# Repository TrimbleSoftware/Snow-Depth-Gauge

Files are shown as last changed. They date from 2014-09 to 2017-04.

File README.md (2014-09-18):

Snow-Depth-Gauge
================

Ultrasonic Wireless Snow Depth Gauge 

Source for Teensy 3.1 Firmware and Eagle 6.5.0 Schematic, 
PCB Layout and Parts list BOM for Trimble Ultrasonic Wireless Snow Depth Gauge.

Uses PRJC Teensy 3.1 microcontroller, MaxBotix ultrasonic sensor and
XBee Series 1 for wireless connectivity.

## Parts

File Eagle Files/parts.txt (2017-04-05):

Mfg Part Num	Mfg Name	VID	Vendor Part Num	Description	Pkg Code
LNJ337W83RA	Panasonic Electronic Components	DK	LNJ337W83RACT-ND	LED GREEN HIGH BRIGHT ESS SMD	0603
LNJ437W84RA	Panasonic Electronic Components	DK	LNJ437W84RACT-ND	LED AMBER HIGH BRIGHT ESS SMD	0603
LNJ237W82RA	Panasonic Electronic Components	DK	LNJ237W82RACT-ND	LED RED HIGH BRIGHT ESS SMD	0603
C1206C104K4RACTU	Kemet	DK	399-9305-1-ND	CAP CER 0.1UF 16V 10% X7R 1206	C3216
KTR18EZPF1102	Rohm Semiconductor	DK	RHM11KAICT-ND	RES 11K OHM 1/4W 1% 1206 SMD	R3216
KTR18EZPF2002	Rohm Semiconductor	DK	RHM20.0KAICT-ND	RES 20K OHM 1/4W 1% 1206 SMD	R3216
MMBT2222A	Fairchild Semiconductor	DK	MMBT2222AFSCT-ND	TRANSISTOR GP NPN AMP SOT-23	SOT23
MMBT4403	Fairchild Semiconductor	DK	MMBT4403FSCT-ND	TRANSISTOR GP PNP AMP SOT-23	SOT23
0022292041	Molex Inc	DK	WM2746-ND	CONN HEADER 4POS .100 VERT GOLD	*
0022292031	Molex Inc	DK	WM2745-ND	CONN HEADER 3POS .100 VERT GOLD	*
0022292021	Molex Inc	DK	WM2744-ND	CONN HEADER 2POS .100 VERT GOLD	*
KTR18EZPF68R0	Rohm Semiconductor	DK	RHM68AICT-ND	RES SMD 68 OHM 1% 1/4W 1206	R3216
KTR18EZPJ103	Rohm Semiconductor	DK	RHM10KPCT-ND	RES 10K OHM 1/4W 5% 1206 SMD	R3216
KTR18EZPF1002	Rohm Semiconductor	DK	RHM10.0KAICT-ND	RES SMD 10K OHM 1% 1/4W 1206	R3216
KTR18EZPF2702	Rohm Semiconductor	DK	RHM27KAICT-ND	RES SMD 27K OHM 1% 1/4W 1206	R3216
KTR18EZPJ104	Rohm Semiconductor	DK	RHM100KPCT-ND	RES 100K OHM 1/4W 5% 1206 SMD	R3216
KTR18EZPJ102	Rohm Semiconductor	DK	RHM1.0KPCT-ND	RES 1K OHM 1/4W 5% 1206 SMD	R3216
KTR18EZPF4701	Rohm Semiconductor	DK	RHM4.7KAICT-ND	RES SMD 4.7K OHM 1% 1/4W 1206 SMD	R3216
KTR18EZPJ221	Rohm Semiconductor	DK	RHM220PCT-ND	RES 220 OHM 1/4W 5% 1206 SMD	R3216
831-87-010-10-001101	Preci-Dip	DK	1212-1314-ND	SOCKET 4.2 MM SOLDER TAIL SINGLE	*
310-87-114-41-001101	Preci-Dip	DK	1212-1101-ND	14 Position Socket Connector 0.100" (2.54mm) Through Hole Gold	*
351-10-114-00-004101	Preci-Dip	DK	1212-1153-ND	14 Positions Header, Unshrouded Connector 0.100" (2.54mm) Through Hole Gold	*
310-87-105-41-001101	Preci-Dip	DK	1212-1094-ND	5 Position Socket Connector 0.100" (2.54mm) Through Hole Gold	*
960114-6202-AR	3M	DK	3M9519-ND	CONN SOCKET SGL VERT 14POS GOLD	*
960105-6202-AR	3M	DK	3M9516-ND	CONN SOCKET SGL VERT 5POS GOLD	*
961114-6404-AR	3M	DK	3M9453-ND	CONN HEADER VERT SGL 14POS GOLD	*
961105-6404-AR	3M	DK	3M9450-ND	CONN HEADER VERT SGL 5POS GOLD	*
PRT-09919	Sparkfun	SF	MOLEX_TO_MOLEX_13_II_07	Molex Jumper 3 Wire Assembly 6" Long	*
PRT-09920	Sparkfun	SF	MOLEX_TO_MOLEX_13_II_07	Molex Jumper 4 Wire Assembly 6" Long	*
XB24-AUI-001	Digi International/Maxstream	DK	XB24-AUI-001-ND	MODULE 802.15.4 1MW W/U.FL CONN	*
RN-UFL-SMA6	Microchip Technology	DK	740-1031-ND	CABLE COAX W/UFL RPSMA 6"	*
W1038	Pulse Electronics Corporation	DK	553-1476-ND	ANTENNA 2.4GHZ HG R-SMA BLK 6.6"	*
MB7957	MaxBotix Inc.	MB	MB7957	HR-MaxTemp MB7957	*
MB7374	MaxBotix Inc.	MB	MB7374	HRXL-MaxSonar - WRS Series Ultrasonic Snow Depth Sensor MB7374	*
TEENSY31	PRJC.COM	PR	TEENSY31	Teensy USB Board, Version 3.1	*
TEENSY32	PRJC.COM	PR	TEENSY32	Teensy USB Board, Version 3.2	*
S2B-PH-SM4-TB(LF)(SN)	JST Sales America Inc	DK	455-1749-1-ND	CONN HEADER PH SIDE 2POS 2MM SMD	*

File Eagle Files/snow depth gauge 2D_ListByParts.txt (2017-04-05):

Part      Value           Attributes Package          Description                                                                     Part Num              Mfg Name                        VID Vendor Part Num         Description                                                                 Pkg Code XREF 
BATT      5VDC                       JST-PH-2-SMT-RA  JST 2-Pin Connectors of various flavors                                         S2B-PH-SM4-TB(LF)(SN) JST Sales America Inc           DK  455-1749-1-ND           CONN HEADER PH SIDE 2POS 2MM SMD                                            *        REF37
C1        0.1uF                      C3216            CAPACITOR, American symbol                                                      C1206C104K4RACTU      Kemet                           DK  399-9305-1-ND           CAP CER 0.1UF 16V 10% X7R 1206                                              C3216    REF4 
D1        GREEN                      LED-0603         Various green LEDs                                                              LNJ337W83RA           Panasonic Electronic Components DK  LNJ337W83RACT-ND        LED GREEN HIGH BRIGHT ESS SMD                                               0603     REF1 
D2        YELLOW                     LED-0603         Yellow SMD LEDs                                                                 LNJ437W84RA           Panasonic Electronic Components DK  LNJ437W84RACT-ND        LED AMBER HIGH BRIGHT ESS SMD                                               0603     REF2 
D3        RED                        LED-0603         Assorted Red LEDs                                                               LNJ237W82RA           Panasonic Electronic Components DK  LNJ237W82RACT-ND        LED RED HIGH BRIGHT ESS SMD                                                 0603     REF3 
JP1       TO MAXBOTIX                MOLEX-1X4        Header 4                                                                        0022292041            Molex Inc                       DK  WM2746-ND               CONN HEADER 4POS .100 VERT GOLD                                             *        REF9 
JP1-1     BOM-ENTRY                  *                BOM ENTRY                                                                       PRT-09920             Sparkfun                        SF  MOLEX_TO_MOLEX_13_II_07 Molex Jumper 4 Wire Assembly 6" Long                                        *        REF29
JP2       M02POLAR                   MOLEX-1X2        Standard 2-pin 0.1" header. Use with                                            0022292021            Molex Inc                       DK  WM2744-ND               CONN HEADER 2POS .100 VERT GOLD                                             *        REF11
JP3       To LiPo Charger            MOLEX-1X4        Header 4                                                                        0022292041            Molex Inc                       DK  WM2746-ND               CONN HEADER 4POS .100 VERT GOLD                                             *        REF9 
JP4       M02POLAR                   MOLEX-1X2        Standard 2-pin 0.1" header. Use with                                            0022292021            Molex Inc                       DK  WM2744-ND               CONN HEADER 2POS .100 VERT GOLD                                             *        REF11
Q1        MMBT2222A                  SOT23-BEC        NPN Transistror                                                                 MMBT2222A             Fairchild Semiconductor         DK  MMBT2222AFSCT-ND        TRANSISTOR GP NPN AMP SOT-23                                                SOT23    REF7 
Q2        MMBT4403LT1SMD             SOT23-BEC        PNP Transistror                                                                 MMBT4403              Fairchild Semiconductor         DK  MMBT4403FSCT-ND         TRANSISTOR GP PNP AMP SOT-23                                                SOT23    REF8 
Q3        MMBT2222A                  SOT23-BEC        NPN Transistror                                                                 MMBT2222A             Fairchild Semiconductor         DK  MMBT2222AFSCT-ND        TRANSISTOR GP NPN AMP SOT-23                                                SOT23    REF7 
Q4        MMBT2222A                  SOT23-BEC        NPN Transistror                                                                 MMBT2222A             Fairchild Semiconductor         DK  MMBT2222AFSCT-ND        TRANSISTOR GP NPN AMP SOT-23                                                SOT23    REF7 
R1        100K                       R3216            RESISTOR, American symbol                                                       KTR18EZPJ104          Rohm Semiconductor              DK  RHM100KPCT-ND           RES 100K OHM 1/4W 5% 1206 SMD                                               R3216    REF16
R2        10K                        R3216            RESISTOR, American symbol                                                       KTR18EZPJ103          Rohm Semiconductor              DK  RHM10KPCT-ND            RES 10K OHM 1/4W 5% 1206 SMD                                                R3216    REF13
R3        10K                        R3216            RESISTOR, American symbol                                                       KTR18EZPJ103          Rohm Semiconductor              DK  RHM10KPCT-ND            RES 10K OHM 1/4W 5% 1206 SMD                                                R3216    REF13
R4        27K                        R3216            RESISTOR, American symbol                                                       KTR18EZPJ273          *                               *   *                       *                                                                           *        *    
R5        220                        R3216            RESISTOR, American symbol                                                       KTR18EZPJ221          Rohm Semiconductor              DK  RHM220PCT-ND            RES 220 OHM 1/4W 5% 1206 SMD                                                R3216    REF19
R6        68                         R3216            RESISTOR, American symbol                                                       KTR18EZPF68R0         Rohm Semiconductor              DK  RHM68AICT-ND            RES SMD 68 OHM 1% 1/4W 1206                                                 R3216    REF12
R7        68                         R3216            RESISTOR, American symbol                                                       KTR18EZPF68R0         Rohm Semiconductor              DK  RHM68AICT-ND            RES SMD 68 OHM 1% 1/4W 1206                                                 R3216    REF12
R8        68                         R3216            RESISTOR, American symbol                                                       KTR18EZPF68R0         Rohm Semiconductor              DK  RHM68AICT-ND            RES SMD 68 OHM 1% 1/4W 1206                                                 R3216    REF12
R9        1K                         R3216            RESISTOR, American symbol                                                       KTR18EZPJ102          Rohm Semiconductor              DK  RHM1.0KPCT-ND           RES 1K OHM 1/4W 5% 1206 SMD                                                 R3216    REF17
R10       10K                        R3216            RESISTOR, American symbol                                                       KTR18EZPJ103          Rohm Semiconductor              DK  RHM10KPCT-ND            RES 10K OHM 1/4W 5% 1206 SMD                                                R3216    REF13
R11       4.7K                       R3216            RESISTOR, American symbol                                                       KTR18EZPF4701         Rohm Semiconductor              DK  RHM4.7KAICT-ND          RES SMD 4.7K OHM 1% 1/4W 1206 SMD                                           R3216    REF18
SENSOR1-1 BOM-ENTRY                  *                BOM ENTRY                                                                       MB7374                MaxBotix Inc.                   MB  MB7374                  HRXL-MaxSonar - WRS Series Ultrasonic Snow Depth Sensor MB7374              *        REF34
SNESOR1-2 BOM-ENTRY                  *                BOM ENTRY                                                                       MB7957                MaxBotix Inc.                   MB  MB7957                  HR-MaxTemp MB7957                                                           *        REF33
U1        TEENSY 3.2                 TEENSY_3.1_BASIC Footprint for Teensy 3.1 board using all pin connections on the outer perimeter TEENSY32              PRJC.COM                        PR  TEENSY32                Teensy USB Board, Version 3.2                                               *        REF36
U1-1      BOM-ENTRY                  *                BOM ENTRY                                                                       310-87-114-41-001101  Preci-Dip                       DK  1212-1101-ND            14 Position Socket Connector 0.100" (2.54mm) Through Hole Gold              *        REF21
U1-2      BOM-ENTRY                  *                BOM ENTRY                                                                       310-87-114-41-001101  Preci-Dip                       DK  1212-1101-ND            14 Position Socket Connector 0.100" (2.54mm) Through Hole Gold              *        REF21
U1-3      BOM-ENTRY                  *                BOM ENTRY                                                                       310-87-105-41-001101  Preci-Dip                       DK  1212-1094-ND            5 Position Socket Connector 0.100" (2.54mm) Through Hole Gold               *        REF23
U1-4      BOM-ENTRY                  *                BOM ENTRY                                                                       351-10-114-00-004101  Preci-Dip                       DK  1212-1153-ND            14 Positions Header, Unshrouded Connector 0.100" (2.54mm) Through Hole Gold *        REF22
U1-5      BOM-ENTRY                  *                BOM ENTRY                                                                       351-10-114-00-004101  Preci-Dip                       DK  1212-1153-ND            14 Positions Header, Unshrouded Connector 0.100" (2.54mm) Through Hole Gold *        REF22
U1-6      BOM-ENTRY                  *                BOM ENTRY                                                                       351-10-114-00-004101  Preci-Dip                       DK  1212-1153-ND            14 Positions Header, Unshrouded Connector 0.100" (2.54mm) Through Hole Gold *        REF22
U2        XBEE-1B1                   XBEE-1           Xbee module footprints                                                          XB24-AUI-001          Digi International/Maxstream    DK  XB24-AUI-001-ND         MODULE 802.15.4 1MW W/U.FL CONN                                             *        REF30
U2-1      BOM-ENTRY                  *                BOM ENTRY                                                                       831-87-010-10-001101  Preci-Dip                       DK  1212-1314-ND            SOCKET 4.2 MM SOLDER TAIL SINGLE                                            *        REF20
U2-2      BOM-ENTRY                  *                BOM ENTRY                                                                       831-87-010-10-001101  Preci-Dip                       DK  1212-1314-ND            SOCKET 4.2 MM SOLDER TAIL SINGLE                                            *        REF20
U2-3      BOM-ENTRY                  *                BOM ENTRY                                                                       RN-UFL-SMA6           Microchip Technology            DK  740-1031-ND             CABLE COAX W/UFL RPSMA 6                                                    *        REF31
U2-4      BOM-ENTRY                  *                BOM ENTRY                                                                       W1038                 Pulse Electronics Corporation   DK  553-1476-ND             ANTENNA 2.4GHZ HG R-SMA BLK 6.6                                             *        REF32

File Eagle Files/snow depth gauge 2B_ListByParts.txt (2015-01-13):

Part      Value           Attributes Package          Description                                                                     Part Num              Mfg Name                        VID Vendor Part Num         Description                                                    Pkg Code XREF 
BATT      5VDC                       JST-PH-2-SMT-RA  JST 2-Pin Connectors of various flavors                                         S2B-PH-SM4-TB(LF)(SN) JST Sales America Inc           DK  455-1749-1-ND           CONN HEADER PH SIDE 2POS 2MM SMD                               *        REF33
C1        0.1uF                      C3216            CAPACITOR, American symbol                                                      C1206C104K4RACTU      Kemet                           DK  399-9305-1-ND           CAP CER 0.1UF 16V 10% X7R 1206                                 C3216    REF4 
D1        GREEN                      LED-0603         Various green LEDs                                                              LNJ337W83RA           Panasonic Electronic Components DK  LNJ337W83RACT-ND        LED GREEN HIGH BRIGHT ESS SMD                                  0603     REF1 
D2        YELLOW                     LED-0603         Yellow SMD LEDs                                                                 LNJ437W84RA           Panasonic Electronic Components DK  LNJ437W84RACT-ND        LED AMBER HIGH BRIGHT ESS SMD                                  0603     REF2 
D3        RED                        LED-0603         Assorted Red LEDs                                                               LNJ237W82RA           Panasonic Electronic Components DK  LNJ237W82RACT-ND        LED RED HIGH BRIGHT ESS SMD                                    0603     REF3 
JP1       TO MAXBOTIX                MOLEX-1X4        Header 4                                                                        0022292041            Molex Inc                       DK  WM2746-ND               CONN HEADER 4POS .100 VERT GOLD                                *        REF9 
JP1-1     BOM-ENTRY                  *                BOM ENTRY                                                                       PRT-09920             Sparkfun                        SF  MOLEX_TO_MOLEX_13_II_07 Molex Jumper 4 Wire Assembly 6" Long                           *        REF26
JP2       M02POLAR                   MOLEX-1X2        Standard 2-pin 0.1" header. Use with                                            0022292021            Molex Inc                       DK  WM2744-ND               CONN HEADER 2POS .100 VERT GOLD                                *        REF11
JP3       To LiPo Charger            MOLEX-1X4        Header 4                                                                        0022292041            Molex Inc                       DK  WM2746-ND               CONN HEADER 4POS .100 VERT GOLD                                *        REF9 
Q1        MMBT2222A                  SOT23-BEC        NPN Transistror                                                                 MMBT2222A             Fairchild Semiconductor         DK  MMBT2222AFSCT-ND        TRANSISTOR GP NPN AMP SOT-23                                   SOT23    REF7 
Q2        MMBT4403LT1SMD             SOT23-BEC        PNP Transistror                                                                 MMBT4403              Fairchild Semiconductor         DK  MMBT4403FSCT-ND         TRANSISTOR GP PNP AMP SOT-23                                   SOT23    REF8 
Q3        MMBT2222A                  SOT23-BEC        NPN Transistror                                                                 MMBT2222A             Fairchild Semiconductor         DK  MMBT2222AFSCT-ND        TRANSISTOR GP NPN AMP SOT-23                                   SOT23    REF7 
Q4        MMBT2222A                  SOT23-BEC        NPN Transistror                                                                 MMBT2222A             Fairchild Semiconductor         DK  MMBT2222AFSCT-ND        TRANSISTOR GP NPN AMP SOT-23                                   SOT23    REF7 
R1        100K                       R3216            RESISTOR, American symbol                                                       KTR18EZPJ104          Rohm Semiconductor              DK  RHM100KPCT-ND           RES 100K OHM 1/4W 5% 1206 SMD                                  R3216    REF17
R2        10K                        R3216            RESISTOR, American symbol                                                       KTR18EZPJ103          Rohm Semiconductor              DK  RHM10KPCT-ND            RES 10K OHM 1/4W 5% 1206 SMD                                   R3216    REF13
R3        10K                        R3216            RESISTOR, American symbol                                                       KTR18EZPF1002         Rohm Semiconductor              DK  RHM10.0KAICT-ND         RES SMD 10K OHM 1% 1/4W 1206                                   R3216    REF14
R4        27K                        R3216            RESISTOR, American symbol                                                       KTR18EZPF2702         Rohm Semiconductor              DK  RHM27KAICT-ND           RES SMD 27K OHM 1% 1/4W 1206                                   R3216    REF16
R5        220                        R3216            RESISTOR, American symbol                                                       KTR18EZPJ221          Rohm Semiconductor              DK  RHM220PCT-ND            RES 220 OHM 1/4W 5% 1206 SMD                                   R3216    REF19
R6        68                         R3216            RESISTOR, American symbol                                                       KTR18EZPJ680          Rohm Semiconductor              DK  RHM68PCT-ND             RES 68 OHM 1/4W 5% 1206 SMD                                    R3216    REF12
R7        68                         R3216            RESISTOR, American symbol                                                       KTR18EZPJ680          Rohm Semiconductor              DK  RHM68PCT-ND             RES 68 OHM 1/4W 5% 1206 SMD                                    R3216    REF12
R8        68                         R3216            RESISTOR, American symbol                                                       KTR18EZPJ680          Rohm Semiconductor              DK  RHM68PCT-ND             RES 68 OHM 1/4W 5% 1206 SMD                                    R3216    REF12
R9        1K                         R3216            RESISTOR, American symbol                                                       KTR18EZPJ102          Rohm Semiconductor              DK  RHM1.0KPCT-ND           RES 1K OHM 1/4W 5% 1206 SMD                                    R3216    REF18
R10       10K                        R3216            RESISTOR, American symbol                                                       KTR18EZPJ103          Rohm Semiconductor              DK  RHM10KPCT-ND            RES 10K OHM 1/4W 5% 1206 SMD                                   R3216    REF13
SENSOR1-1 BOM-ENTRY                  *                BOM ENTRY                                                                       MB7374                MaxBotix Inc.                   MB  MB7374                  HRXL-MaxSonar - WRS Series Ultrasonic Snow Depth Sensor MB7374 *        REF31
SNESOR1-2 BOM-ENTRY                  *                BOM ENTRY                                                                       MB7957                MaxBotix Inc.                   MB  MB7957                  HR-MaxTemp MB7957                                              *        REF30
U1        TEENSY 3.1                 TEENSY_3.1_BASIC Footprint for Teensy 3.1 board using all pin connections on the outer perimeter TEENSY31              PRJC.COM                        PR  TEENSY31                Teensy USB Board, Version 3.1                                  *        REF32
U1-1      BOM-ENTRY                  *                BOM ENTRY                                                                       961114-6404-AR        3M                              DK  3M9453-ND               CONN HEADER VERT SGL 14POS GOLD                                *        REF23
U1-2      BOM-ENTRY                  *                BOM ENTRY                                                                       961114-6404-AR        3M                              DK  3M9453-ND               CONN HEADER VERT SGL 14POS GOLD                                *        REF23
U1-3      BOM-ENTRY                  *                BOM ENTRY                                                                       961105-6404-AR        3M                              DK  3M9450-ND               CONN HEADER VERT SGL 5POS GOLD                                 *        REF24
U2        XBEE-1B1                   XBEE-1           Xbee module footprints                                                          XB24-AUI-001          Digi International/Maxstream    DK  XB24-AUI-001-ND         MODULE 802.15.4 1MW W/U.FL CONN                                *        REF27
U2-1      BOM-ENTRY                  *                BOM ENTRY                                                                       831-87-010-10-001101  Preci-Dip                       DK  1212-1314-ND            SOCKET 4.2 MM SOLDER TAIL SINGLE                               *        REF20
U2-2      BOM-ENTRY                  *                BOM ENTRY                                                                       831-87-010-10-001101  Preci-Dip                       DK  1212-1314-ND            SOCKET 4.2 MM SOLDER TAIL SINGLE                               *        REF20
U2-3      BOM-ENTRY                  *                BOM ENTRY                                                                       RN-UFL-SMA6           Microchip Technology            DK  740-1031-ND             CABLE COAX W/UFL RPSMA 6                                       *        REF28
U2-4      BOM-ENTRY                  *                BOM ENTRY                                                                       W1038                 Pulse Electronics Corporation   DK  553-1476-ND             ANTENNA 2.4GHZ HG R-SMA BLK 6.6                                *        REF29

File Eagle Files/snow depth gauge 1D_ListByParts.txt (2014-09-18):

Part      Value          Attributes Package          Description                                                                     Part Num             Mfg Name                        VID Vendor Part Num         Description                                                    Pkg Code XREF 
C1        0.1uF                     C3216            CAPACITOR, American symbol                                                      C1206C104K4RACTU     Kemet                           DK  399-9305-1-ND           CAP CER 0.1UF 16V 10% X7R 1206                                 1206     REF4 
D1        GREEN                     LED-0603         Various green LEDs                                                              LNJ337W83RA          Panasonic Electronic Components DK  LNJ337W83RACT-ND        LED GREEN HIGH BRIGHT ESS SMD                                  0603     REF1 
D2        YELLOW                    LED-0603         Yellow SMD LEDs                                                                 LNJ437W84RA          Panasonic Electronic Components DK  LNJ437W84RACT-ND        LED AMBER HIGH BRIGHT ESS SMD                                  0603     REF2 
D3        RED                       LED-0603         Assorted Red LEDs                                                               LNJ237W82RA          Panasonic Electronic Components DK  LNJ237W82RACT-ND        LED RED HIGH BRIGHT ESS SMD                                    0603     REF3 
JP1       TO MAXBOTIX               MOLEX-1X3_LOCK   Header 3                                                                        0022292031           Molex Inc                       DK  WM2745-ND               CONN HEADER 3POS .100 VERT GOLD                                2.54mm   REF9 
JP1-1     BOM-ENTRY                 *                BOM ENTRY                                                                       PRT-09919            Sparkfun                        SF  MOLEX_TO_MOLEX_13_II_07 Molex Jumper 3 Wire Assembly                                   2.54mm   REF20
Q1                                  SOT23-BEC        NPN Transistror                                                                 MMBT2222A            Fairchild Semiconductor         DK  MMBT2222AFSCT-ND        TRANSISTOR GP NPN AMP SOT-23                                   SOT-23   REF7 
Q2        MMBT4403LT1SMD            SOT23-BEC        PNP Transistror                                                                 MMBT4403             Fairchild Semiconductor         DK  MMBT4403FSCT-ND         TRANSISTOR GP PNP AMP SOT-23                                   SOT-23   REF8 
Q3                                  SOT23-BEC        NPN Transistror                                                                 MMBT2222A            Fairchild Semiconductor         DK  MMBT2222AFSCT-ND        TRANSISTOR GP NPN AMP SOT-23                                   SOT-23   REF7 
Q4                                  SOT23-BEC        NPN Transistror                                                                 MMBT2222A            Fairchild Semiconductor         DK  MMBT2222AFSCT-ND        TRANSISTOR GP NPN AMP SOT-23                                   SOT-23   REF7 
R1        100K                      R3216            RESISTOR, American symbol                                                       KTR18EZPJ104         Rohm Semiconductor              DK  RHM100KPCT-ND           RES 100K OHM 1/4W 5% 1206 SMD                                  1206     REF12
R2        10K                       R3216            RESISTOR, American symbol                                                       KTR18EZPJ103         Rohm Semiconductor              DK  RHM10KPCT-ND            RES 10K OHM 1/4W 5% 1206 SMD                                   1206     REF11
R3        11K                       R3216            RESISTOR, American symbol                                                       KTR18EZPF1102        Rohm Semiconductor              DK  RHM11KAICT-ND           RES 11K OHM 1/4W 1% 1206 SMD                                   1206     REF5 
R4        20K                       R3216            RESISTOR, American symbol                                                       KTR18EZPF2002        Rohm Semiconductor              DK  RHM20.0KAICT-ND         RES 20K OHM 1/4W 1% 1206 SMD                                   1206     REF6 
R5        220                       R3216            RESISTOR, American symbol                                                       KTR18EZPJ221         Rohm Semiconductor              DK  RHM220PCT-ND            RES 220 OHM 1/4W 5% 1206 SMD                                   1206     REF14
R6        68                        R3216            RESISTOR, American symbol                                                       KTR18EZPJ680         Rohm Semiconductor              DK  RHM68PCT-ND             RES 68 OHM 1/4W 5% 1206 SMD                                    1206     REF10
R7        68                        R3216            RESISTOR, American symbol                                                       KTR18EZPJ680         Rohm Semiconductor              DK  RHM68PCT-ND             RES 68 OHM 1/4W 5% 1206 SMD                                    1206     REF10
R8        68                        R3216            RESISTOR, American symbol                                                       KTR18EZPJ680         Rohm Semiconductor              DK  RHM68PCT-ND             RES 68 OHM 1/4W 5% 1206 SMD                                    1206     REF10
R9        1K                        R3216            RESISTOR, American symbol                                                       KTR18EZPJ102         Rohm Semiconductor              DK  RHM1.0KPCT-ND           RES 1K OHM 1/4W 5% 1206 SMD                                    1206     REF13
SENSOR1-1 BOM-ENTRY                 *                BOM ENTRY                                                                       MB7374               MaxBotix Inc.                   MB  MB7374                  HRXL-MaxSonar - WRS Series Ultrasonic Snow Depth Sensor MB7374 *        REF25
SNESOR1-2 BOM-ENTRY                 *                BOM ENTRY                                                                       MB7957               MaxBotix Inc.                   MB  MB7957                  HR-MaxTemp MB7957                                              *        REF24
U1        TEENSY 3.1                TEENSY_3.1_BASIC Footprint for Teensy 3.1 board using all pin connections on the outer perimeter TEENSY31             PRJC.COM                        PR  TEENSY31                Teensy USB Board, Version 3.1                                  *        REF26
U1-1      BOM-ENTRY                 *                BOM ENTRY                                                                       961114-6404-AR       3M                              DK  3M9453-ND               CONN HEADER VERT SGL 14POS GOLD                                2.54mm   REF18
U1-2      BOM-ENTRY                 *                BOM ENTRY                                                                       961114-6404-AR       3M                              DK  3M9453-ND               CONN HEADER VERT SGL 14POS GOLD                                2.54mm   REF18
U1-3      BOM-ENTRY                 *                BOM ENTRY                                                                       961105-6404-AR       3M                              DK  3M9450-ND               CONN HEADER VERT SGL 5POS GOLD                                 2.54mm   REF19
U2        XBEE-1B1                  XBEE-1           Xbee module footprints                                                          XB24-AUI-001         Digi International/Maxstream    DK  XB24-AUI-001-ND         MODULE 802.15.4 1MW W/U.FL CONN                                2.00mm   REF21
U2-1      BOM-ENTRY                 *                BOM ENTRY                                                                       831-87-010-10-001101 Preci-Dip                       DK  1212-1314-ND            SOCKET 4.2 MM SOLDER TAIL SINGLE                               2.00mm   REF15
U2-2      BOM-ENTRY                 *                BOM ENTRY                                                                       831-87-010-10-001101 Preci-Dip                       DK  1212-1314-ND            SOCKET 4.2 MM SOLDER TAIL SINGLE                               2.00mm   REF15
U2-3      BOM-ENTRY                 *                BOM ENTRY                                                                       RN-UFL-SMA6          Microchip Technology            DK  740-1031-ND             CABLE COAX W/UFL RPSMA 6                                       *        REF22
U2-4      BOM-ENTRY                 *                BOM ENTRY                                                                       W1038                Pulse Electronics Corporation   DK  553-1476-ND             ANTENNA 2.4GHZ HG R-SMA BLK 6.6                                *        REF23

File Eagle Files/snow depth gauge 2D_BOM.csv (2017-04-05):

Qty-4 | Part References | Value | Package | Mfg Part Num | Mfg Name | VID | Vendor Part Num | Description | Pkg Code | XREF
4 | C1 | 0.1uF | C3216 | C1206C104K4RACTU | Kemet | DK | 399-9305-1-ND | CAP CER 0.1UF 16V 10% X7R 1206 | C3216 | REF4
4 | R9 | 1K | R3216 | KTR18EZPJ102 | Rohm Semiconductor | DK | RHM1.0KPCT-ND | RES 1K OHM 1/4W 5% 1206 SMD | R3216 | REF17
4 | R11 | 4.7K | R3216 | KTR18EZPF4701 | Rohm Semiconductor | DK | RHM4.7KAICT-ND | RES SMD 4.7K OHM 1% 1/4W 1206 SMD | R3216 | REF18
4 | BATT | 5VDC | JST-PH-2-SMT-RA | S2B-PH-SM4-TB(LF)(SN) | JST Sales America Inc | DK | 455-1749-1-ND | CONN HEADER PH SIDE 2POS 2MM SMD | * | REF37
12 | R2, R3, R10 | 10K | R3216 | KTR18EZPJ103 | Rohm Semiconductor | DK | RHM10KPCT-ND | RES 10K OHM 1/4W 5% 1206 SMD | R3216 | REF13
4 | R4 | 27K | R3216 | ***PART# 'KTR18EZPJ273' NOT FOUND*** | * | * | * | * | * | *
12 | R6, R7, R8 | 68 | R3216 | KTR18EZPF68R0 | Rohm Semiconductor | DK | RHM68AICT-ND | RES SMD 68 OHM 1% 1/4W 1206 | R3216 | REF12
4 | R1 | 100K | R3216 | KTR18EZPJ104 | Rohm Semiconductor | DK | RHM100KPCT-ND | RES 100K OHM 1/4W 5% 1206 SMD | R3216 | REF16
4 | R5 | 220 | R3216 | KTR18EZPJ221 | Rohm Semiconductor | DK | RHM220PCT-ND | RES 220 OHM 1/4W 5% 1206 SMD | R3216 | REF19
4 | U1-3 | BOM-ENTRY | * | 310-87-105-41-001101 | Preci-Dip | DK | 1212-1094-ND | 5 Position Socket Connector 0.100" (2.54mm) Through Hole Gold | * | REF23
8 | U1-1, U1-2 | BOM-ENTRY | * | 310-87-114-41-001101 | Preci-Dip | DK | 1212-1101-ND | 14 Position Socket Connector 0.100" (2.54mm) Through Hole Gold | * | REF21
12 | U1-4, U1-5, U1-6 | BOM-ENTRY | * | 351-10-114-00-004101 | Preci-Dip | DK | 1212-1153-ND | 14 Positions Header | Unshrouded Connector 0.100" (2.54mm) Through Hole Gold | * | REF22
8 | U2-1, U2-2 | BOM-ENTRY | * | 831-87-010-10-001101 | Preci-Dip | DK | 1212-1314-ND | SOCKET 4.2 MM SOLDER TAIL SINGLE | * | REF20
4 | SENSOR1-1 | BOM-ENTRY | * | MB7374 | MaxBotix Inc. | MB | MB7374 | HRXL-MaxSonar - WRS Series Ultrasonic Snow Depth Sensor MB7374 | * | REF34
4 | SNESOR1-2 | BOM-ENTRY | * | MB7957 | MaxBotix Inc. | MB | MB7957 | HR-MaxTemp MB7957 | * | REF33
4 | JP1-1 | BOM-ENTRY | * | PRT-09920 | Sparkfun | SF | MOLEX_TO_MOLEX_13_II_07 | Molex Jumper 4 Wire Assembly 6" Long | * | REF29
4 | U2-3 | BOM-ENTRY | * | RN-UFL-SMA6 | Microchip Technology | DK | 740-1031-ND | CABLE COAX W/UFL RPSMA 6 | * | REF31
4 | U2-4 | BOM-ENTRY | * | W1038 | Pulse Electronics Corporation | DK | 553-1476-ND | ANTENNA 2.4GHZ HG R-SMA BLK 6.6 | * | REF32
4 | D1 | GREEN | LED-0603 | LNJ337W83RA | Panasonic Electronic Components | DK | LNJ337W83RACT-ND | LED GREEN HIGH BRIGHT ESS SMD | 0603 | REF1
8 | JP2, JP4 | M02POLAR | MOLEX-1X2 | 0022292021 | Molex Inc | DK | WM2744-ND | CONN HEADER 2POS .100 VERT GOLD | * | REF11
12 | Q1, Q3, Q4 | MMBT2222A | SOT23-BEC | MMBT2222A | Fairchild Semiconductor | DK | MMBT2222AFSCT-ND | TRANSISTOR GP NPN AMP SOT-23 | SOT23 | REF7
4 | Q2 | MMBT4403LT1SMD | SOT23-BEC | MMBT4403 | Fairchild Semiconductor | DK | MMBT4403FSCT-ND | TRANSISTOR GP PNP AMP SOT-23 | SOT23 | REF8
4 | D3 | RED | LED-0603 | LNJ237W82RA | Panasonic Electronic Components | DK | LNJ237W82RACT-ND | LED RED HIGH BRIGHT ESS SMD | 0603 | REF3
4 | U1 | TEENSY 3.2 | TEENSY_3.1_BASIC | TEENSY32 | PRJC.COM | PR | TEENSY32 | Teensy USB Board | Version 3.2 | * | REF36
8 | JP1, JP3 | To LiPo Charger | MOLEX-1X4 | 0022292041 | Molex Inc | DK | WM2746-ND | CONN HEADER 4POS .100 VERT GOLD | * | REF9
4 | U2 | XBEE-1B1 | XBEE-1 | XB24-AUI-001 | Digi International/Maxstream | DK | XB24-AUI-001-ND | MODULE 802.15.4 1MW W/U.FL CONN | * | REF30
4 | D2 | YELLOW | LED-0603 | LNJ437W84RA | Panasonic Electronic Components | DK | LNJ437W84RACT-ND | LED AMBER HIGH BRIGHT ESS SMD | 0603 | REF2

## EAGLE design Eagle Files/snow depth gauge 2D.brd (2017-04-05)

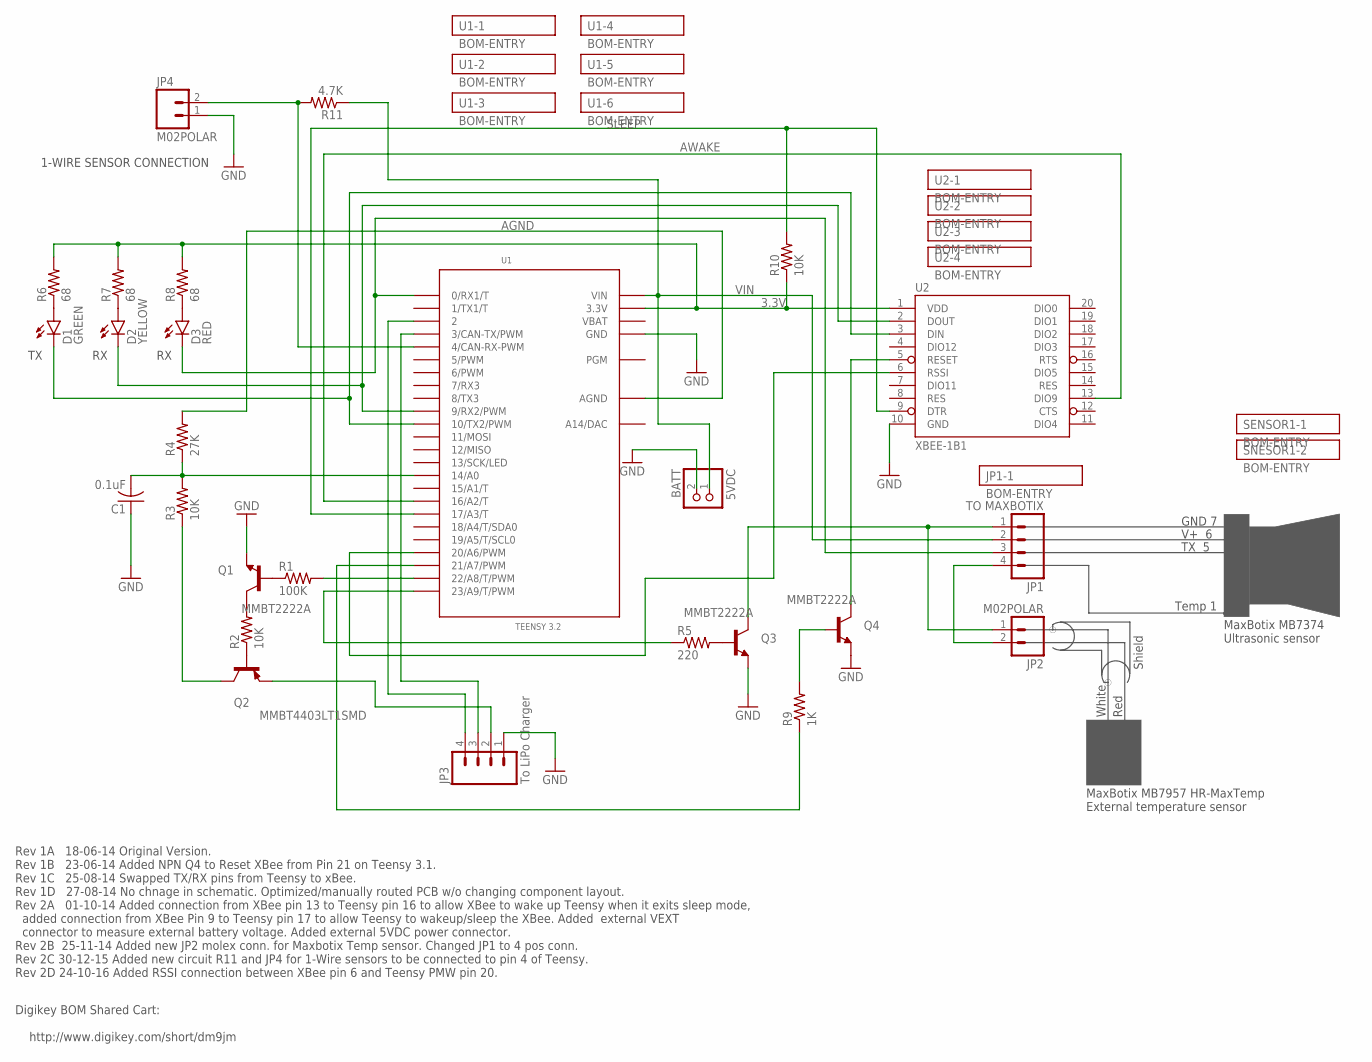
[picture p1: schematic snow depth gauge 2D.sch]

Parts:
BATT: 5VDC; JST-PH-2-SMT-RA; PARTNO S2B-PH-SM4-TB(LF)(SN)
C1: 0.1uF; C3216; PARTNO C1206C104K4RACTU
D1: GREEN; LED-0603; PARTNO LNJ337W83RA
D2: YELLOW; LED-0603; PARTNO LNJ437W84RA
D3: RED; LED-0603; PARTNO LNJ237W82RA
JP1: TO MAXBOTIX; MOLEX-1X4; PARTNO 0022292041
JP2, JP4: M02POLAR; MOLEX-1X2; PARTNO 0022292021
JP3: To LiPo Charger; MOLEX-1X4; PARTNO 0022292041
Q1, Q3, Q4: MMBT2222A; SOT23-BEC; PARTNO MMBT2222A
Q2: MMBT4403LT1SMD; SOT23-BEC; PARTNO MMBT4403
R1: 100K; R3216; PARTNO KTR18EZPJ104
R2, R3, R10: 10K; R3216; PARTNO KTR18EZPJ103
R4: 27K; R3216; PARTNO KTR18EZPJ273
R5: 220; R3216; PARTNO KTR18EZPJ221
R6, R7, R8: 68; R3216; PARTNO KTR18EZPF68R0
R9: 1K; R3216; PARTNO KTR18EZPJ102
R11: 4.7K; R3216; PARTNO KTR18EZPF4701
U1: TEENSY 3.2; TEENSY_3.1_BASIC; PARTNO TEENSY32
U2: XBEE-1B1; XBEE-1; PARTNO XB24-AUI-001

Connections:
3.3V: R6.2, R7.2, R8.2, R10.1, U1.3.3V, U1.3.3V1 (3.3V), U2.1 (VDD)
22: R1.2, U1.22/A8 (22/A8/T/PWM)
23: R5.1, U1.23/A9 (23/A9/T/PWM)
A0: C1.2, R3.2, R4.1, U1.14/A0
AGND: R4.2, U1.AGND
AWAKE: U1.16/A2 (16/A2/T), U2.13 (DIO9)
GND: BATT.2 (1), C1.1, JP3.1, JP4.1, Q1.E, Q3.E, Q4.E, U1.GND, U1.GND1 (GND), U2.10 (GND)
IN: D2.C, U1.9 (9/RX2/PWM), U2.2 (DOUT)
MBGND: JP1.1, JP2.1, Q3.C
MBTEMP: JP1.4, JP2.2
unnamed: D3.A, R8.1
unnamed: Q4.B, R9.2
unnamed: Q4.C, U2.5 (RESET)
unnamed: JP3.2, Q2.E
unnamed: Q3.B, R5.2
unnamed: Q1.B, R1.1
unnamed: Q1.C, R2.2
unnamed: Q2.B, R2.1
unnamed: D1.A, R6.1
unnamed: JP4.2, R11.2, U1.4 (4/CAN-RX-PWM)
unnamed: Q2.C, R3.1
unnamed: D2.A, R7.1
OUT: D1.C, U1.10 (10/TX2/PWM), U2.3 (DIN)
RESET: R9.1, U1.21/A7 (21/A7/PWM)
RSSI: U1.20/A6 (20/A6/PWM), U2.6 (RSSI)
RX1: D3.C, JP1.3, U1.0 (0/RX1/T)
SLEEP: R10.2, U1.17/A3 (17/A3/T), U2.9 (DTR)
STAT1: JP3.4, U1.2
STAT2: JP3.3, U1.3 (3/CAN-TX/PWM)
VBAT: U1.VBAT
VIN: BATT.1 (2), JP1.2, R11.1, U1.VIN

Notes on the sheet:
Rev 1A 18-06-14 Original Version. Rev 1B 23-06-14 Added NPN Q4 to Reset XBee from Pin 21 on Teensy 3.1. Rev 1C 25-08-14 Swapped TX/RX pins from Teensy to xBee. Rev 1D 27-08-14 No chnage in schematic. Optimized/manually routed PCB w/o changing component layout. Rev 2A 01-10-14 Added connection from 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
Digikey BOM Shared Cart: http://www.digikey.com/short/dm9jm
GND 7
V+ 6
TX 5
MaxBotix MB7374 Ultrasonic sensor
Temp 1
MaxBotix MB7957 HR-MaxTemp External temperature sensor
Red
White
Shield
1-WIRE SENSOR CONNECTION

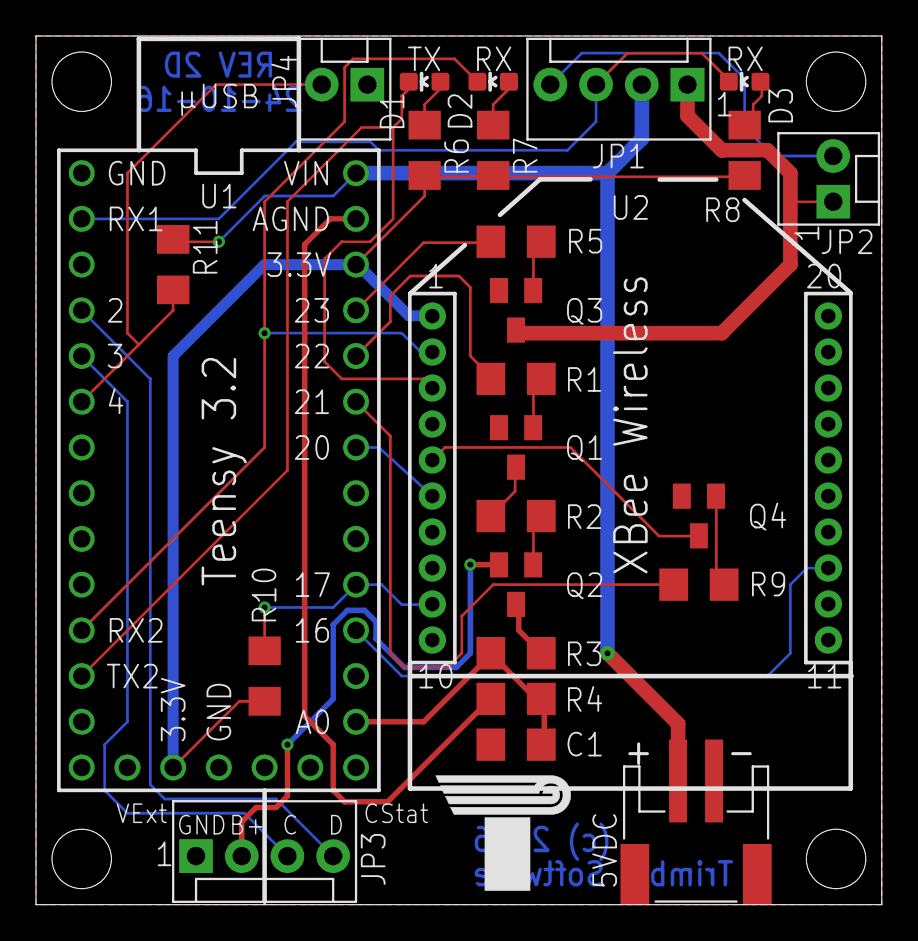
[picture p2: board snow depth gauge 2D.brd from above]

Board: 2 copper layers, 47.0 x 48.3 mm, 32 parts (0 on the bottom side), 30 nets.

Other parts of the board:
U$1, U$2, U$3, U$4: STAND-OFF
U$5: LOGO_4
U$6: LOGO_4_BOTTOM

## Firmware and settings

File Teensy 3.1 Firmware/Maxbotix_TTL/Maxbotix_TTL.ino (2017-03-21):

/*

 Teensy 3.1/3.2 sketch that implements a snow depth gauge for use with XBee wireless communication with meteohub to log
 snow depth data using a Maxbotix ultrasonic range finder snow depth sensor.
 
 Written:  Version 1.0  10-June-2014 Trimble Software, Anchorage, AK
 Modified: Version 1.0a 19-June-2014 Changed error codes to 1000x the values to make them more obvious. Also changed how
                                       serial device readiness is detected to be able to tell if Maxbotix sensor has failed or
                                       is disconnected. Also added XBee reset functionality.
           Version 1.1  25-June-2014 Added watchdog timer per http://forum.pjrc.com/threads/25370-Teensy-3-0-Watchdog-Timer
           Version 1.2  06-Aug-2014  Fixed bug with errors not being returned on Range command.
           Version 1.3  17-Sep-2014  Added lowpower sleep.
           Version 1.4  01-Oct-2014  Cleaned up some code having to do with XBee reset.
           Version 1.5  04-Sep-2015  Code changes for hardware ver 2B integration with Adafriut solar charger http://www.adafruit.com/products/390
                                       and xBee hardware wake/sleep on pin 17. http://www.fiz-ix.com/2012/11/low-power-xbee-sleep-mode-with-arduino-and-pin-hibernation/
           Version 1.6  21-Sep-2016  Code changes to build with Arduino 1.6.11 and Teensyduino 1.30 and LowPower_Teensy3 library.
           Version 1.6a 29-Sep-2016  Fixed buffer overflow on string operations that was causing Teensy to hang sometimes.
           Version 1.6b 03-Oct-2016  Chunk xBee output into 63 byte chunks to prevent xBee on-board buffer overflow.
           Version 1.6c 20-Nov-2016  Revert code back to compile with Arduino 1.0.6 and Teensyduino 1.20 to try and get wathdog timer working properly.
           Version 1.6d 22-Nov-2016  Added new command I to display firmware build info.
           Version 1.6e 05-Jan-2017  Added code to clear incomming serial data after current command has completed in at attempt to discard bad data that sometime hangs the teensy.
           Version 1.7a 20-Mar-2017  Added new command N to read XBee RSSI from pin 6 using PWM and display as relative signal strength percentage.
           
 Maxbotix HRXL-Maxsonar MB7354 Teensy 3.1/3.2 TTL interface
 
 Hookup:
 
 Teensy 3.1/.2 Pin Maxbotix MB7354 Pin
 ---------------   ---------------
    GND             7  GND via NPN transistor to have 3.3 VDC pin switch 5.0 VDC supply to Maxbotix sensor via low side switching
    Vin             6  V+
 0  RX1             5  Serial Output TTL
  23 Digital Out     to Base of NPN transistor via 220 ohm 1/4 pullup resistor used to switch 5.0 VDC supply of Maxbotix sensor
 
 Teensy 3.1/3.2 Pins:
                     220 Ohm
     23 +-----------/\/\--------------+
                                      | B
                                     ___      NPN NTE123AP
                                  E /   \ C
                                   |    |
                                   |    |
    Gnd +--------------------------+    |
                                        |
Maxbotix Pins                           |
    7   +-------------------------------+
    
    6   +---------+ Vin                                   
 
                    XBee pin
                    --------
    GND             10 GND
    3.3V            1  VDD
 9  RX2             2  DOUT
 10 TX2             3  DIN
 16                 13 DIO9 To signal when XBee is awake
 17                 9  DTR  To use Pin Mode sleep/wake on XBee
 
                  1K Ohm
 21 +------------/\/\------------+
                                 | B
                                ___     NPN NTE123AP
                             E /   \ C
                               |   |
                               |   |
 Gnd +-------------------------+   |
                                   |
                                   |
XBee Pin 5 RESET +-----------------+

                   Adafruit solar charger
                   ---------------
 2                  D
 3                  C
 

Tips on accessing gauge from a Linux host:
  Use this command line to send commands directly to the gauge:
    echo -n "V" > /dev/ttyMHsd1 ; cat /dev/ttyMHsd1
  
  The tty serial port baud rate has to be sent from the command line to send manual commands:
    stty -F /dev/ttyMHsd1 38400

*/

#include <math.h>
#include <EEPROM.h>
#include <LowPower_Teensy3.h> // duff's Teensy 3 low power library https://github.com/duff2013/LowPower_Teensy3

// #define DEBUG 1
#define SWVER "1.7a 03/16/17"
#define HWVER "2D"
#define STRINGBUFSIZE 256

#define ABOUT "Trimble Ultrasonic Wireless Snow Depth Gauge - Ver"
#define CHAR_CR    0x0d
#define CHAR_R     0x52

#define CPU_RESTART_ADDR (uint32_t *)0xE000ED0C
#define CPU_RESTART_VAL 0x5FA0004
#define CPU_RESTART (*CPU_RESTART_ADDR = CPU_RESTART_VAL);

#define RANGE_MAX 4999
#define RANGE_MIN 500
#define RANGE_NO_TARGET 5000
#define AUTO_RANGE_DELAY 500

// commands
#define CMD_GET_ABOUT 'A'
#define CMD_RESTART 'B' // restart Teensy CPU
#define CMD_SET_CALIBRATE 'C'
#define CMD_GET_DEPTH 'D'
#define CMD_GET_CALIBRATION 'G'
#define CMD_GET_BUILDINFO 'I'
#define CMD_GET_RSSI 'N' // XBee signal RSSI
#define CMD_GET_RANGE 'R'
#define CMD_SET_MANUAL_CALIBRATE 'S'
#define CMD_GET_CHARGE_STATUS 'T' // get LiPo battery charger status
#define CMD_GET_BATT_VOLTS 'V'
#define CMD_HELP '?'

// errors
#define ERR_NONE       0
#define ERR_NO_DATA   -1000
#define ERR_NO_TARGET -2000
#define ERR_TOO_CLOSE -3000
#define ERR_BAD_DATUM -4000
#define ERR_NO_SENSOR -5000 

// Teensy I/O pins
#define MAXBOTIXPOWERPIN   23 // pin to drive Base of NPN transistor to control power to Maxbotix sensor
#define VOLTAGEPOWERPIN    22 // pin to drive Base of NPN transistor to control power to voltage divider circuit
#define XBEERESETPIN       21 // pin to drive base of NPN transistor to pull low to cause XBee module to reset
#define XBEESLEEPPIN       17 // pin to control XBee wake/sleep via pin 9 on the xBee
#define XBEEAWAKEPIN       16 // pin to detect if XBee is awake
#define XBEERSSIPIN        20 // pin to read PWM signal output on XBee pin 6
#define DONE_CHARGING_PIN  2  // pin to test if Adafruit solar charger is done charging
#define STILL_CHARGING_PIN 3  // pin to test if Adafruit solar charger is still charging
#define ADCPIN      A0

#define LED_DIM     128
#define LED_BRIGHT  255
#define BLINK_LONG  500
#define BLINK_SHORT 1
#define ADCSAMPLES  10 // number of ADC samples to take and average for reading battery voltage

// status codes for Adafruit solar charger
#define STATUS_DONE_CHARGING 2
#define STATUS_CHARGING      1
#define STATUS_NOT_CHARGING  0

// to take cpu out of low power mode to be able to write to EEPROM 
#define TWENTYFOUR_MHZ 24000000

// watchdog
#define RCM_SRS0_WAKEUP                     0x01
#define RCM_SRS0_LVD                        0x02
#define RCM_SRS0_LOC                        0x04
#define RCM_SRS0_LOL                        0x08
#define RCM_SRS0_WDOG                       0x20
#define RCM_SRS0_PIN                        0x40
#define RCM_SRS0_POR                        0x80

#define RCM_SRS1_LOCKUP                     0x02
#define RCM_SRS1_SW                         0x04
#define RCM_SRS1_MDM_AP                     0x08
#define RCM_SRS1_SACKERR                    0x20

// globals
TEENSY3_LP lp = TEENSY3_LP();
HardwareSerial_LP Uart1 = HardwareSerial_LP(); // RX1 for Maxbotix sensor. TX1 is not used.
HardwareSerial2_LP Uart2 = HardwareSerial2_LP(); // RX2/TX2 for XBee
const char ascii_nul = '\0';
const char ascii_0 = '0';
const char ascii_9 = '9';
const char outputFormat[] = "%c%04.4d\n";

IntervalTimer wdTimer;

void XBeeSleep(int SleepPin)
{
  // put the XBee to sleep
#ifdef DEBUG
  Serial.printf("Putting XBee to sleep...\n");
#endif
  pinMode(SleepPin, INPUT); // put pin in a high impedence state
  digitalWrite(SleepPin, HIGH);  
}

void XBeeWake(int WakePin)
{
  // wake up the XBee
#ifdef DEBUG
  Serial.printf("Waking XBee...\n");
#endif
  pinMode(WakePin, OUTPUT);
  digitalWrite(WakePin, LOW);  
}

boolean isXBeeAwake(int AwakePin)
{
  // is XBee awake?  
  pinMode(AwakePin, INPUT_PULLUP);
  int isAwake = digitalRead(AwakePin);
#ifdef DEBUG
  Serial.printf("XBee is Awake: %d\n", isAwake);
#endif
  return (isAwake > 0? true: false);
}

#define XBEEBUFFERSIZE 63
int XBeePrintf(HardwareSerial2_LP port, boolean flickerLED, const char *format, ...)
{
  char buf[STRINGBUFSIZE];
  memset(buf, ascii_nul, sizeof(buf));
  va_list args;
  int done = -1;
 
  if(!isXBeeAwake(XBEEAWAKEPIN)) // if XBee is asleep,
  {
    XBeeWake(XBEESLEEPPIN); // wake it up
    delay(10); // delay to allow XBee time to wakeup
  }
 
  va_start (args, format);
  vsnprintf(buf, sizeof(buf), format, args);
  va_end(args);
  port.clear();
  int i = 0;
  i = strlen(buf);
#ifdef DEBUG
  Serial.print(buf);
  Serial.println(i);
#endif

  if(i > XBEEBUFFERSIZE) // break long strings up into 63 byte chunks to fit into xBee on-board buffer
  {
    char *s;
    s = buf;
    char buf64[XBEEBUFFERSIZE+1];
    memset(buf64, ascii_nul, XBEEBUFFERSIZE+1);
    for(int j = 1; j <= (int)(i / XBEEBUFFERSIZE); j++)
    {
      strncpy(buf64, s, XBEEBUFFERSIZE);
#ifdef DEBUG      
      Serial.println(buf64);
#endif      
      done = port.print(buf64);
      delay(10);
      memset(buf64, ascii_nul, XBEEBUFFERSIZE+1);
      s = buf + (XBEEBUFFERSIZE * j);
    }
    memset(buf64, ascii_nul, XBEEBUFFERSIZE+1);
    strncpy(buf64, s, i % XBEEBUFFERSIZE);
#ifdef DEBUG
    Serial.println(i % XBEEBUFFERSIZE);
    Serial.print(buf64);
#endif     
    done = port.print(buf64);
    delay(10);
  }
  else
  {
    done = port.print(buf);
    delay(10);
  }
  
  port.flush();

  if(flickerLED)
    blinkLED_BuiltIn(BLINK_SHORT, LED_DIM); // flicker the built in Teensy LED
    
  XBeeSleep(XBEESLEEPPIN); // put XBee back to sleep
  
  return done;
}

int getRange(HardwareSerial_LP port)
{
  char buf[6] = {0,0,0,0,0,0};
  #define READING_COUNT 9
  int sensorReading[READING_COUNT];
  int range = ERR_NO_DATA;
#ifdef DEBUG  
  analogWrite(LED_BUILTIN, LED_DIM);
#endif  
  digitalWrite(MAXBOTIXPOWERPIN, HIGH); // turn on/boot Maxbotix Sensor
  delay(AUTO_RANGE_DELAY); // delay to allow full auto-range filtering to take place
  for(int i = 0; i < READING_COUNT; i++)
  {
    port.setTimeout(20);
    if(port.readBytes(buf, 1) != 0) // sensor or data available on the TTL UART interface?
    {
      port.clear();
      delay(10);
      while(port.peek() != CHAR_R)
        port.read(); // read until 'R' is found
      port.setTimeout(1000);  
      port.readBytesUntil(CHAR_CR, buf, sizeof(buf)); // read range from Maxbotix sensor
      if
      (
          buf[0] == CHAR_R &&
          (buf[1] >= ascii_0 && buf[1] <= ascii_9) && 
          (buf[2] >= ascii_0 && buf[2] <= ascii_9) &&
          (buf[3] >= ascii_0 && buf[3] <= ascii_9) && 
          (buf[4] >= ascii_0 && buf[4] <= ascii_9)
      )
        sensorReading[i] = (buf[1] - ascii_0) * 1000 + (buf[2] - ascii_0) * 100 + (buf[3] - ascii_0) * 10 + (buf[4] - ascii_0); // convert 4 digit ASCII char number to binary number
      else
        sensorReading[i] = ERR_NO_DATA; // error getting data from sensor
    }
    else
      sensorReading[i] = ERR_NO_SENSOR;
  }
  digitalWrite(MAXBOTIXPOWERPIN, LOW); // turn off Maxbotix Sensor
 #ifdef DEBUG 
  digitalWrite(LED_BUILTIN, LOW);
#endif

  range = mode(sensorReading, READING_COUNT); // get the mode common reading out of mulitple

  if(range == RANGE_NO_TARGET)
    range = ERR_NO_TARGET;
  else
  if(range == RANGE_MIN)
    range = ERR_TOO_CLOSE;

  port.clear();
  port.flush();
  
  return range; 
}

// read sensor to get current height and then store in Teensy EEPROM
int setDatum (HardwareSerial_LP port)
{
  int datum = 0;
  datum = getRange(port);
#ifdef DEBUG
  Serial.printf("ranged datum: %d", datum);
#endif
  writeDatum(datum);
  return datum;
}

// write 16 bit sensor mounting height datum into Teensy EEPROM at locations 0 and 1
void writeDatum (int datum)
{
  lp.CPU(TWENTYFOUR_MHZ); // exit low power mode to be able to write EEPROM
  EEPROM.write(0, (datum & 0xff00) / 0x100);
  EEPROM.write(1, datum & 0xff);
  lp.CPU(TWO_MHZ); // go back to low power mode after EEPROM write
}

// get 16 bit sensor datum from Teensy EEPROM at locationa 0 and 1
int getDatum()
{
  int datum = 0;
  datum = (EEPROM.read(0) * 0x100) + EEPROM.read(1); 
#ifdef DEBUG
  Serial.print("raw EEPROM bytes: ");
  Serial.print(EEPROM.read(0), HEX);
  Serial.print(" ");
  Serial.println(EEPROM.read(1), HEX);
  Serial.print("datum read from EEPROM: ");
  Serial.println(datum, DEC);
#endif
  return datum;
}

// get Maxbotix sensor boot info
void getSensorInfo (HardwareSerial_LP port1, HardwareSerial2_LP port2)
{
  char buf[6][STRINGBUFSIZE];

  digitalWrite(MAXBOTIXPOWERPIN, HIGH); // turn on/boot Maxbotix Sensor  
  delay(100);
  if(port1.available())
  {
    for(int i = 0; i < 6; i++) // 6 lines of boot data
    {
      memset(buf[i], ascii_nul, sizeof(buf[i]));
      port1.readBytesUntil(CHAR_CR, buf[i], sizeof(buf[i])); // read boot messages from Maxbotix sensor  
    }
    for(int i = 0; i < 6; i++) // 6 lines of boot data
    {
          XBeePrintf(port2, false, "%s\n", buf[i]);
    }
  }
  digitalWrite(MAXBOTIXPOWERPIN, LOW); // turn off Maxbotix Sensor
}

void blinkLED_BuiltIn(int duration, int brightness)
{
  analogWrite(LED_BUILTIN, brightness); // on
  delay(duration);
  digitalWrite(LED_BUILTIN, LOW); // off
}

// get statistical Mode of an array of ints
// adapapted from http://playground.arduino.cc/Main/Average
int mode(int *data, int count)
{
  int pos;
  int inner;
  int most;
  int mostcount;
  int current;
  int currentcount;

  most = 0;
  mostcount = 0;
  for(pos = 0; pos < count; pos++)
  {
    current = data[pos];
    currentcount = 0;
    for(inner = pos + 1; inner < count; inner++)
    {
      if(data[inner] == current)
        currentcount++;
    }
    if(currentcount > mostcount)
    {
      most = current;
      mostcount = currentcount;
    }
    // If we have less array slices left than the current
    // maximum count, then there is no room left to find
    // a bigger count.  We have finished early and we can
    // go home.
    if(count - pos < mostcount)
      break;
  }
  return most;
}
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
void loop()
{ 
#ifdef DEBUG
  Serial.printf("Sleeping...\n");
#endif
  // put Teensy to sleep, interrupt on UART input from XBee will wake it up
  lp.Sleep();
#ifdef DEBUG
  Serial.printf("Awakened\n");
#endif
  processCommand();
}

void processCommand(void)
{
  int datum = 0;
  int range = 0;
  int depth = 0;
  int volts = 0; // battery volts * 100
  char commandByte = 0;
  
  if(Uart2.available())
  {
    commandByte = Uart2.read();   
    switch(commandByte)
    {
      case CMD_GET_ABOUT: // about
      {
        printAbout(Uart2);
        getSensorInfo(Uart1, Uart2);
        blinkLED_BuiltIn(BLINK_SHORT, LED_DIM);
        break;
      }
        
      case CMD_RESTART: // restart CPU
      {
#ifdef DEBUG
        XBeePrintf(Uart2, false, "%s\n", "CPU Resetting...");
#endif         
        blinkLED_BuiltIn(BLINK_LONG, LED_BRIGHT);
        delay(50);
        blinkLED_BuiltIn(BLINK_LONG, LED_BRIGHT);
        delay(50);
        blinkLED_BuiltIn(BLINK_LONG, LED_BRIGHT);
        delay(50);
#ifdef DEBUG        
        XBeePrintf(Uart2, false, "%s\n", "XBee Resetting...");
        delay(50);
#endif        
        ResetXBee(XBEERESETPIN); // Reset XBee
        delay(500);
        CPU_RESTART;
        break;
      }

      case CMD_SET_CALIBRATE: // calibrate mounting height and store into EEPROM, send results out serial
      {
        int datumAsSet = 0;
        datumAsSet = setDatum(Uart1);
        datum = getDatum();
        if (datum != datumAsSet) // check to see that value stored is same value read from EEPROM
          datum = ERR_BAD_DATUM;
        else
          XBeePrintf(Uart2, true, outputFormat, CMD_SET_CALIBRATE, datum);
          
        break;
      }

      case CMD_GET_DEPTH: // read snow depth and send out serial
      {
        datum = getDatum();
        range = getRange(Uart1);
        if(range < 0)
          depth = range;
        else
        if(range < datum)
          depth = datum - range;
        else
          depth = 0;
          
        XBeePrintf(Uart2, true, outputFormat, CMD_GET_DEPTH, depth);
        break;
      }

      case CMD_GET_CALIBRATION: // get saved datum saved in EEPROM and send out serial
      {
        datum = getDatum();
        XBeePrintf(Uart2, true, outputFormat, CMD_GET_CALIBRATION, datum);
        break;
      }
      
      case CMD_GET_BUILDINFO: // get firmware build info and send out serial
      {
        printBuildInfo(Uart2);
       break; 
      }
      
      case CMD_GET_RSSI: // read XBee RSSI value stored from last serial read
      {
        int r = 0;      
        r = ((int)((getRssi(XBEERSSIPIN) * 100) + 0.5)) * 100;
        XBeePrintf(Uart2, true, outputFormat, CMD_GET_RSSI, r);
        break; 
      }
      
      case CMD_GET_RANGE: // read sensor range and send out serial
      {
        range = getRange(Uart1);
        XBeePrintf(Uart2, true, outputFormat, CMD_GET_RANGE, range);
        break;
      }

      case CMD_SET_MANUAL_CALIBRATE: // set manual datum and save into EEPROM, reread and send out serial
      {
        char buf[5] = {0,0,0,0,0};
        Uart2.readBytesUntil(CHAR_CR, buf, sizeof(buf));
        if
        (
          (buf[0] >= ascii_0 && buf[0] <= ascii_9) && 
          (buf[1] >= ascii_0 && buf[1] <= ascii_9) &&
          (buf[2] >= ascii_0 && buf[2] <= ascii_9) && 
          (buf[3] >= ascii_0 && buf[3] <= ascii_9)
        )
        {
          datum = (buf[0] - ascii_0) * 1000 + (buf[1] - ascii_0) * 100 + (buf[2] - ascii_0) * 10 + (buf[3] - ascii_0);
          writeDatum(datum);
          datum = getDatum();
        }
        else
          datum = ERR_BAD_DATUM;

        XBeePrintf(Uart2, true, outputFormat, CMD_SET_MANUAL_CALIBRATE, datum);
        break;
      }
      
      case CMD_GET_CHARGE_STATUS: // get Adafruit solar charger status
      {
        int chargeStatus = -1;
        int stillCharging = digitalRead(STILL_CHARGING_PIN);
        int doneCharging = digitalRead(DONE_CHARGING_PIN);

        switch (doneCharging << 1 | stillCharging)
        {
          case 1: // done charging
            chargeStatus = STATUS_DONE_CHARGING;
            break;
          case 2: // charging
            chargeStatus = STATUS_CHARGING;
            break;
          case 3: // not charging
            chargeStatus = STATUS_NOT_CHARGING;
            break;
          default: // shouldn't be possible
            chargeStatus = -1;
            break;
        }
        
        XBeePrintf(Uart2, true, outputFormat, CMD_GET_CHARGE_STATUS, chargeStatus);
        break;
      }
      case CMD_GET_BATT_VOLTS: // get battery voltage and send out serial
      {
#ifdef DEBUG          
        float v = 0.0;
        v = getVolts();
        XBeePrintf(Uart2, false, "%d\n", v);
#endif   
        volts = (int)((getVolts() * 100.0) + 0.5);
        XBeePrintf(Uart2, true, outputFormat, CMD_GET_BATT_VOLTS, volts);
        break;
      }
      case CMD_HELP: // list commands
      {
        printCommands(Uart2);
        break;        
      }
      default:
      {
#ifdef DEBUG
        Serial.printf("\nUnknown commandByte: 0x%0x", commandByte);
#endif
        break;
      }
    }
    Uart2.clear();
  }
}

void printResetType() 
{
  if (RCM_SRS1 & RCM_SRS1_SACKERR)   Serial.println("[RCM_SRS1] - Stop Mode Acknowledge Error Reset");
  if (RCM_SRS1 & RCM_SRS1_MDM_AP)    Serial.println("[RCM_SRS1] - MDM-AP Reset");
  if (RCM_SRS1 & RCM_SRS1_SW)        Serial.println("[RCM_SRS1] - Software Reset");
  if (RCM_SRS1 & RCM_SRS1_LOCKUP)    Serial.println("[RCM_SRS1] - Core Lockup Event Reset");
  if (RCM_SRS0 & RCM_SRS0_POR)       Serial.println("[RCM_SRS0] - Power-on Reset");
  if (RCM_SRS0 & RCM_SRS0_PIN)       Serial.println("[RCM_SRS0] - External Pin Reset");
  if (RCM_SRS0 & RCM_SRS0_WDOG)      Serial.println("[RCM_SRS0] - Watchdog(COP) Reset");
  if (RCM_SRS0 & RCM_SRS0_LOC)       Serial.println("[RCM_SRS0] - Loss of External Clock Reset");
  if (RCM_SRS0 & RCM_SRS0_LOL)       Serial.println("[RCM_SRS0] - Loss of Lock in PLL Reset");
  if (RCM_SRS0 & RCM_SRS0_LVD)       Serial.println("[RCM_SRS0] - Low-voltage Detect Reset");
}

#ifdef __cplusplus
extern "C" {
#endif
  void startup_early_hook() {
    WDOG_TOVALL = 3000; // The next 2 lines sets the time-out value. This is the value that the watchdog timer compares itself to.
    WDOG_TOVALH = 0;
    WDOG_STCTRLH = (WDOG_STCTRLH_ALLOWUPDATE | WDOG_STCTRLH_WDOGEN | WDOG_STCTRLH_WAITEN | WDOG_STCTRLH_STOPEN); // Enable WDG
    //WDOG_PRESC = 0; // prescaler
    if (PMC_REGSC & PMC_REGSC_ACKISO) TEENSY3_LP::wakeSource = (LLWU_F1 | LLWU_F2<<8 | LLWU_F3<<16);
  }
#ifdef __cplusplus
}
#endif

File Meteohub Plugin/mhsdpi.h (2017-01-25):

/*

	mhsdpi.h

*/
/*
	includes
*/
#include <stdlib.h>
#include <termios.h>
#include <stdio.h>
#include <sys/types.h>
#include <sys/stat.h>
#include <fcntl.h>
#include <stdint.h>
#include <unistd.h>
#include <limits.h>
#include <string.h>
#include <time.h>
#include <malloc.h>
#include <math.h>

#include "fdget.h" // fd based lib that uses poll() for tty  I/O
/*
	defines
*/
#define true 1
#define false 0
///#define MAXREADINGS 10 // number of readings to use for moving average smoothing
#define MAXREADINGS 5 // number of readings to use for moving average smoothing

// commands
#define CMD_GET_ABOUT 'A'
#define CMD_RESTART 'B' // restart teensey CPU
#define CMD_SET_CALIBRATE 'C'
#define CMD_GET_DEPTH 'D'
#define CMD_GET_CALIBRATION 'G'
#define CMD_GET_RANGE 'R'
#define CMD_SET_MANUAL_CALIBRATE 'S'
#define CMD_GET_CHARGER_STATUS 'T'
#define CMD_GET_VOLTAGE 'V'

/*
	constants
*/

/*
	typedefs
*/
typedef unsigned char boolean;

/*
	structs
*/
struct args_t
{
	boolean restart_remote_sensor; 	// -B switch
	boolean close_tty_file;			// -C switch
	char *device;					// -d value
	boolean set_auto_datum;			// -D switch
	boolean write_log;				// -L switch
	uint16_t manual_datum;			// -s value
	boolean  set_manual_datum;
	uint16_t sleep_seconds;			// -t value.
};

struct config_t
{
	boolean restart_remote_sensor;
	boolean close_tty_file;
	char device[FILENAME_MAX];
	boolean set_auto_datum;
	boolean write_log;
	char log_file_name[FILENAME_MAX];
	char readings_file_name[FILENAME_MAX];
	uint16_t manual_datum;
	boolean  set_manual_datum;
	uint16_t sleep_seconds;
	uint16_t stdev_filter;
	uint16_t retry_count;
};

/*
	function prototypes
*/
int get_initial_sensor (int *values, int datum, int fd, uint16_t retry_count);
int write_array(const int *values, int n, char *filename);
int read_array(int *values,int n, char *filename);
float moving_average(int *values, int n, int new_value);
float average(const int *values, int n);
float standard_deviation(const int *values, int n);
void print_firmware_version(int fd, char *logfilename, char *myname);
int get_calibration_value(int fd, uint16_t retry_count);
int set_calibration_value(int fd, uint16_t retry_count);
int set_manual_calibration_value(int fd, int value);
int get_depth_value(int fd, int retry_count);
int get_range_value(int fd, uint16_t retry_count);
int get_battery_voltage(int fd, int retry_count);
int get_charger_status(int fd, int retry_count);
boolean restart_sensor(int fd);

int set_tty_port(int ttyfile, char *device, char* myname, char *log_file_name, boolean writetolog);
uint32_t get_seconds_since_midnight (void);
void writelog (char *logfilename, char *process_name, char *message);
void display_usage(char *myname);
int get_configuration(struct config_t *config, char *path);

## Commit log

2014-09-18 Teensy 3.1 sketch source
    Version 1.3 of Teensy/Maxbotix Snow Depth Gauge
2014-09-18 Eagle Files
    Eagle files for PCB fabrication.
    [snow depth gauge 1D.brd, snow depth gauge 1D.sch]
2014-09-18 Revert "Eagle Files"
    This reverts commit d98600f46fc9b085ccf87501f4de8b5395eab803.
    [snow depth gauge 1D.brd, snow depth gauge 1D.sch]
2014-09-18 Teensy 3.1 Firmware
    Teensy 3.1 sketch for Snow Depth Gauge Firmware
2014-09-18 Eagle Files
    Eagle Files for PCB Fabrication and BOM
    [snow depth gauge 1D.brd, snow depth gauge 1D.sch]
2014-09-18 Meteohub Plugin
    gcc source for meteohub plug-in for Trimble Ultrasonic Wireless Snow
    Depth Gauge
2014-10-02 Remote reset fixes
    Fixed problem with remote sensor reset on plugin startup
    [Maxbotix_TTL.ino]
2014-10-02 Improved PCB version 2A. Not tested yet.
    Designed to interface to Adafriut Solar LiPo Charger for Status Charging
    and Done, connection to XBee sleep pin and measurement of voltage from
    external source (ala external LiPo battery).
    [snow depth gauge 2A.brd, snow depth gauge 2A.sch]
2014-10-24 Added outlier removal and data smoothing
    Added outlier removal and data smoothing. any value that is more than 3
    standard deviations away from the mean of the last 10 readings is
    replaced by the average of the last 10 readings. Data is now smoothed
    using a moving average (aka rolling average) of the last 10 readings.
    Also added a test program to demonstrate the smoothing and a utility to
    dump the binary array stored in a file of the last 10 readings.
    [mhsdpi.h]
2014-11-10 Ver. 1.2
    Added Standard Deviation filter limit value to .config file. Also
    re-read array from disc at end of polling loop to allow changes to be
    made to the moving average values with out restarting the program.
2014-11-26 PCB Ver. 2B
    Further Improved PCB Version 2B. Not tested yet. Has 4 pin and Molex
    conn. for Maxbotix snow sensor and 2 pin Molex conn. for Maxbotix Temp
    sensor and 4 pin Molex for LiPo charger connections.
    [snow depth gauge 2B.brd, snow depth gauge 2B.sch]
2014-11-27 Ver 1.3
    Ver 1.3 Changed to read sma array values from sensor at startup instead
    from saved file. Added logic to get_depth_value
    and get_range_value to allow better reporting on specific sensor errors.
2014-11-28 Ver 1.4
    Fix spelling typo
    [Maxbotix_TTL.ino]
2014-12-03 Ver 1.4
    Added retry logic to depth, range and auto calibrate functions
2015-01-13 PCB Ver. 2B Voltage Divider Update
    Updated voltage divider components and values for measuring external 4.2
    VDC LiPo battery.
    [snow depth gauge 2B.brd, snow depth gauge 2B.sch]
2015-05-07 Makefile for raspbian on PI 2
    Changes to Makefile for raspbian running on Raspberry PI 2 B host.
2015-09-06 Ver 1.5
    Code changes for hardware ver 2B integration with Adafriut solar charger
    http://www.adafruit.com/products/390
    and xBee hardware wake/sleep on pin 17.
    http://www.fiz-ix.com/2012/11/low-power-xbee-sleep-mode-with-arduino-and-pin-hibernation/
2015-09-07 Ver 1.7
    Ver 1.7 Added LiPo charger status output for Snow Depth Gauge Version
    2B-1.5
2016-07-08 Updates for Arduino 1.6.6
    Updated to compile with Arduino 1.6.6 by commenting out #ifdefs for
    _cextern "C" on startup_early_hook() function.
2016-09-14 Bumped minor version mumber
    Bumped minor version for Arduino 1.6.6 compiled binary
2016-09-23 Changes for Arduino 1.6.11 and Teensyduino 1.30
    Code changes to build with Arduino 1.6.11 and Teensyduino 1.30 and
    LowPower_Teensy3 library.
2016-11-21 Revert back to Arduino 1.0.6 and Teensyduino 1.20
    Revert code back to compile with Arduino 1.0.6 and Teensyduino 1.20 to
    try and get wathdog timer working properly.
    [Maxbotix_TTL.ino]
2017-01-06 Added code to clear incomming serial data after current command has completed.
    Version 1.6e 05-Jan-2017 Added code to clear incomming serial data
    after current command has completed in at attempt to discard bad data
    that sometime hangs the teensy.
2017-01-06 Version 1.6e 05-Jan-2017
    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
2017-01-12 Ver 1.7a more minor bug fixes
    minor bug fixes for sensor readings file config and writing.
2017-01-25 Ver 2.0
    Ver 2.0 changed i/o to fd non-buffered using poll() and looping to
    read/write tty data and added retry logic to sensor reading functions.
2017-01-25 Revert "Ver 2.0"
    This reverts commit 12273f9cdc06bfb025c33b7855a577ee9c001226.
    [mhsdpi.h]
2017-01-25 Ver 2.0
    read/write tty data and added retry logic to some sensor reading
    functions.
    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
2017-02-01 Ver 2.0a
    Ver 2.0a added main loop exit via return codes propigated through sensor
    readings. To allow meteohub to restart plugin when comm errors occure.
2017-03-13 Ver 2.0b
    Ver 2.0b bug fixes in avarage amd moving average functions and initial
    sensor readings functions.
2017-03-21 Version 1.7a
    Version 1.7a 20-Mar-2017 Added new command N to read XBee RSSI from pin
    6 using PWM and display as relative signal strength percentage.
2017-04-05 Eagle files for PCB Ver 2D 24-10-16
    Added RSSI conection between XBee pin 6 and Teensy PWN pin 20
    [snow depth gauge 2D.brd, snow depth gauge 2D.sch, snow depth gauge 2D_BOM.csv]

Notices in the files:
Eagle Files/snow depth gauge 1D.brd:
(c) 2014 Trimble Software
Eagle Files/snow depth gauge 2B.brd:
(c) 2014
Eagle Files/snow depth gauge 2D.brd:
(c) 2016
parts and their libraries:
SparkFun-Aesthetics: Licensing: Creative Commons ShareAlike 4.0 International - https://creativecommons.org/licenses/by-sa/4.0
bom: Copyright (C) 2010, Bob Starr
